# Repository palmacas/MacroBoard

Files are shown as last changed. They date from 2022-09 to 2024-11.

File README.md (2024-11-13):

# MacroBoard

MacroBoard

MacroBoard is a 9-key hot-swappable mechanical macropad powered by [Seeed Studio XIAO RP2040](https://www.seeedstudio.com/XIAO-RP2040-v1-0-p-5026.html). The keyboard has 9 Kailh hot-swappable sockets compatible with any 3-pin or 5-pin MX switch, giving you the ability to choose the switches that suit you best. The keyboard also includes a rotary encoder with a push button and each key is backlit with an RGB LED.

## Features

- Uses Seeed XIAO RP2040, a small form factor board based on the Raspberry Pi RP2040 microcontroller.
- Supports MicroPython and CircuitPython.
- Kailh hot-swappable sockets compatible with 3-pin and 5-pin MX switches.
- Rotary quadrature encoder with push button.
- SK6812 reverse-mounted addressable RGB LEDs to backlight each key.
- Power and communication through a USB-C type port.
- Compatible with KMK keyboard firmware.
- Compatible with Windows, macOS, and Linux operating systems.
- Dimensions: 61mm x 81mm x 31mm (without case), 66mm x 86mm x 35mm (with 3D-printed case).

## Hardware Overview

MacroBoard

## Getting Started

To set up the keyboard to work with CircuitPython and KMK Firmware, follow these steps:

### CircuitPython Installation

1. Enter Bootloader Mode
   - Press and hold the "BOOT" button.
   - Connect the Seeed XIAO RP2040 to your computer while still holding the button.
   - Your computer should now show a new drive, RPI-RP2.
2. Download the [firmware](https://circuitpython.org/board/seeeduino_xiao_rp2040/) for Seeed Studio XIAO RP2040.
3. Drag the .uf2 file to the drive RPI-RP2.
4. Check the drive. The name should now have changed to CIRCUITPY.

### NeoPixel Support 

5. Download the file [*neopixel.py*](https://github.com/adafruit/Adafruit_CircuitPython_NeoPixel/blob/main/neopixel.py) and copy it to the root directory on drive CIRCUITPY.

### KMK Installation

6. Download the [KMK Firmware](https://github.com/KMKfw/kmk_firmware) repository as a ZIP file.
7. Extract all files from de ZIP file and copy the *kmk* folder to the root directory on drive CIRCUITPY.
8. Download the files *code.py* and *boot.py* from the [firmware](firmware) folder.
9. Copy the files to the drive CIRCUITPY.
10. Restart the keyboard by pressing the "RESET" button or disconnecting and reconnecting to the computer.

### Keyboard Configuration

The key mapping defines the function and behavior of each key using a keycode or set of keycodes. The following code, which can be found in the file *code.py*, shows the key mapping for MacroBoard.

```python
# Keymap
keyboard.keymap = [
    [KC.LCTRL(KC.LSHIFT(KC.TAB)), KC.LCTRL(KC.M), KC.LCTRL(KC.TAB),
     KC.MEDIA_PREV_TRACK, KC.MEDIA_PLAY_PAUSE, KC.MEDIA_NEXT_TRACK,
     KC.LCTRL(KC.C), KC.LCTRL(KC.V), KC.LGUI(KC.SPACE),
    ]
]
```
In this example, the keys in the first row can switch between browser tabs and mute a tab. The keys in the second row can control the media player, and the keys in the third row function as `Ctrl+C`, `Ctrl+V`, and `GUI+SPACE`.

||COLUMN 1 |COLUMN 2 | COLUMN 3|
|---|---|---|---|
|ROW 1|CTRL+SHIFT+TAB |CTRL+M |CTRL+TAB |
|ROW 2|PREV TRACK |PLAY/PAUSE |NEXT TRACK |
|ROW 3|CTRL+C |CTRL+V |GUI+SPACE|

You can find a list of all available keycodes at the [KMK Firmware's](http://kmkfw.io/docs/keycodes) wiki.

## Disclaimer

The CircuitPython firmware, KMK Firmware, and NeoPixel library are managed and maintained by their respective developers.

---
More information:  
[MacroBoard – Design and Assembly](https://palmacas.com/macroboard-design/) [[Spanish]](https://palmacas.com/macroboard-diseno/)  
[MacroBoard – Configuration](https://palmacas.com/macroboard-configuration/) [[Spanish]](https://palmacas.com/macroboard-configuracion/)

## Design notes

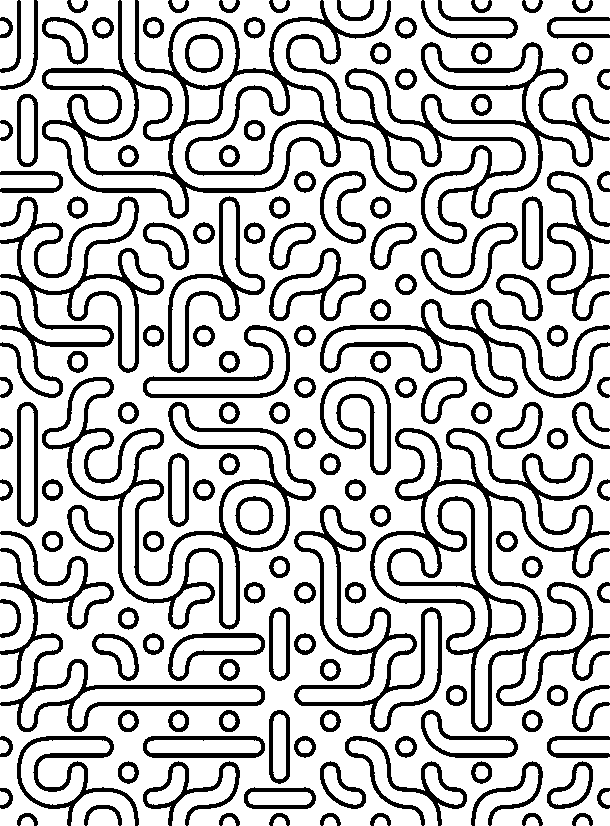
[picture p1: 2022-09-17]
PCB/TruchetTiles.bmp

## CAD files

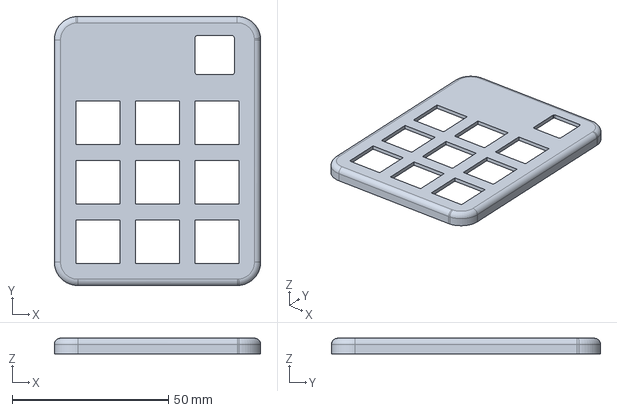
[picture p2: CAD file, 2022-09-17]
CAD/MacroBoardCover.step
66.0 x 86.0 x 5.00 mm

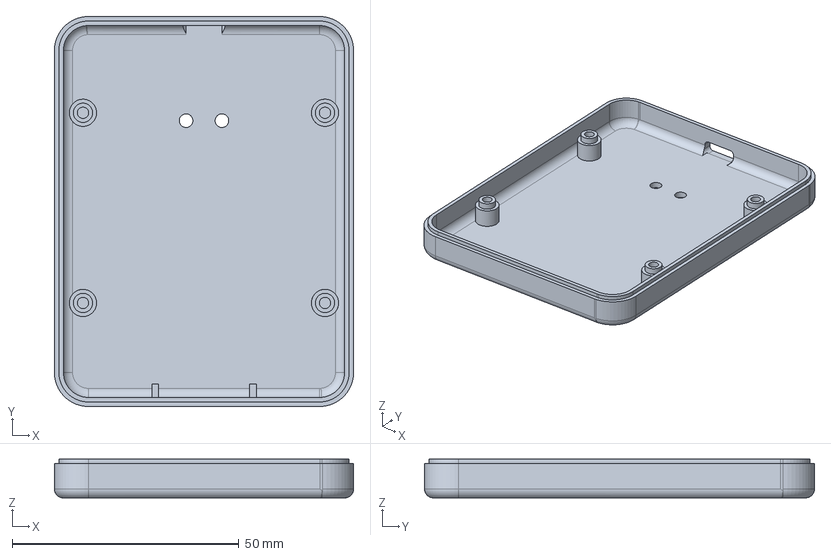
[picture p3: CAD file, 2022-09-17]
CAD/MacroBoardBase.step
66.0 x 86.0 x 8.56 mm

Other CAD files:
CAD/MacroBoardBase.stl
CAD/MacroBoardCover.stl

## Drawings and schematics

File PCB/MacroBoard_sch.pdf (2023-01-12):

# ROTA COL1

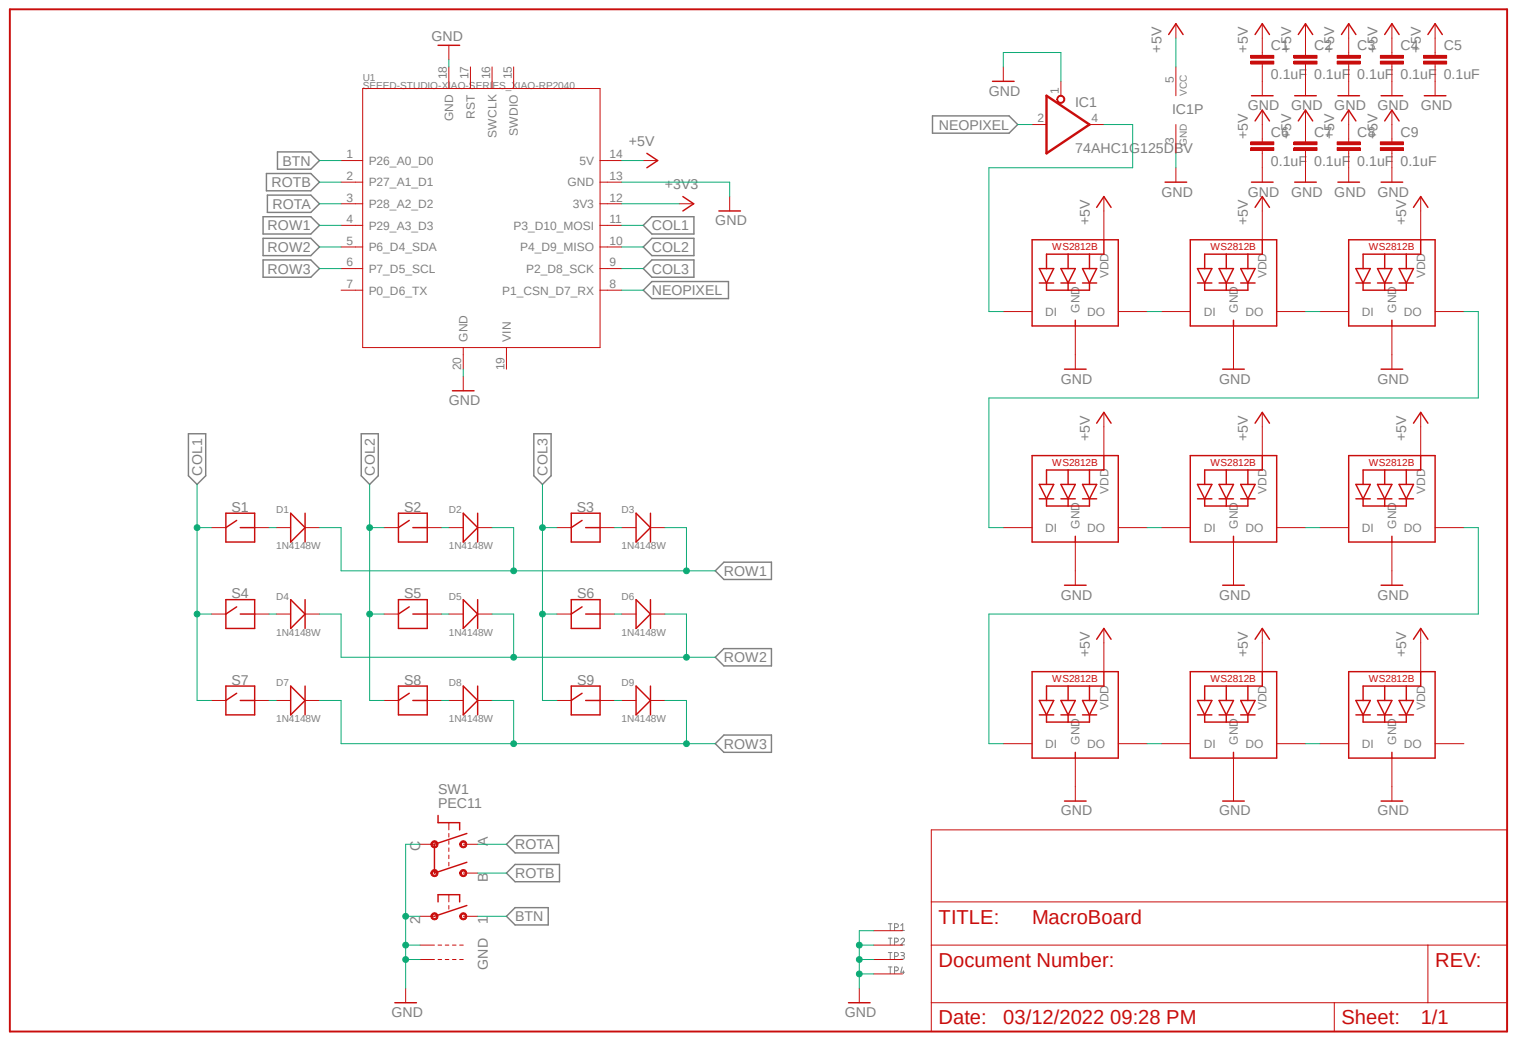
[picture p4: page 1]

GND GND

DI GND DO VDD

Document Number: | REV:

Date: 03/12/2022 09:28 PM | Sheet: 1/1

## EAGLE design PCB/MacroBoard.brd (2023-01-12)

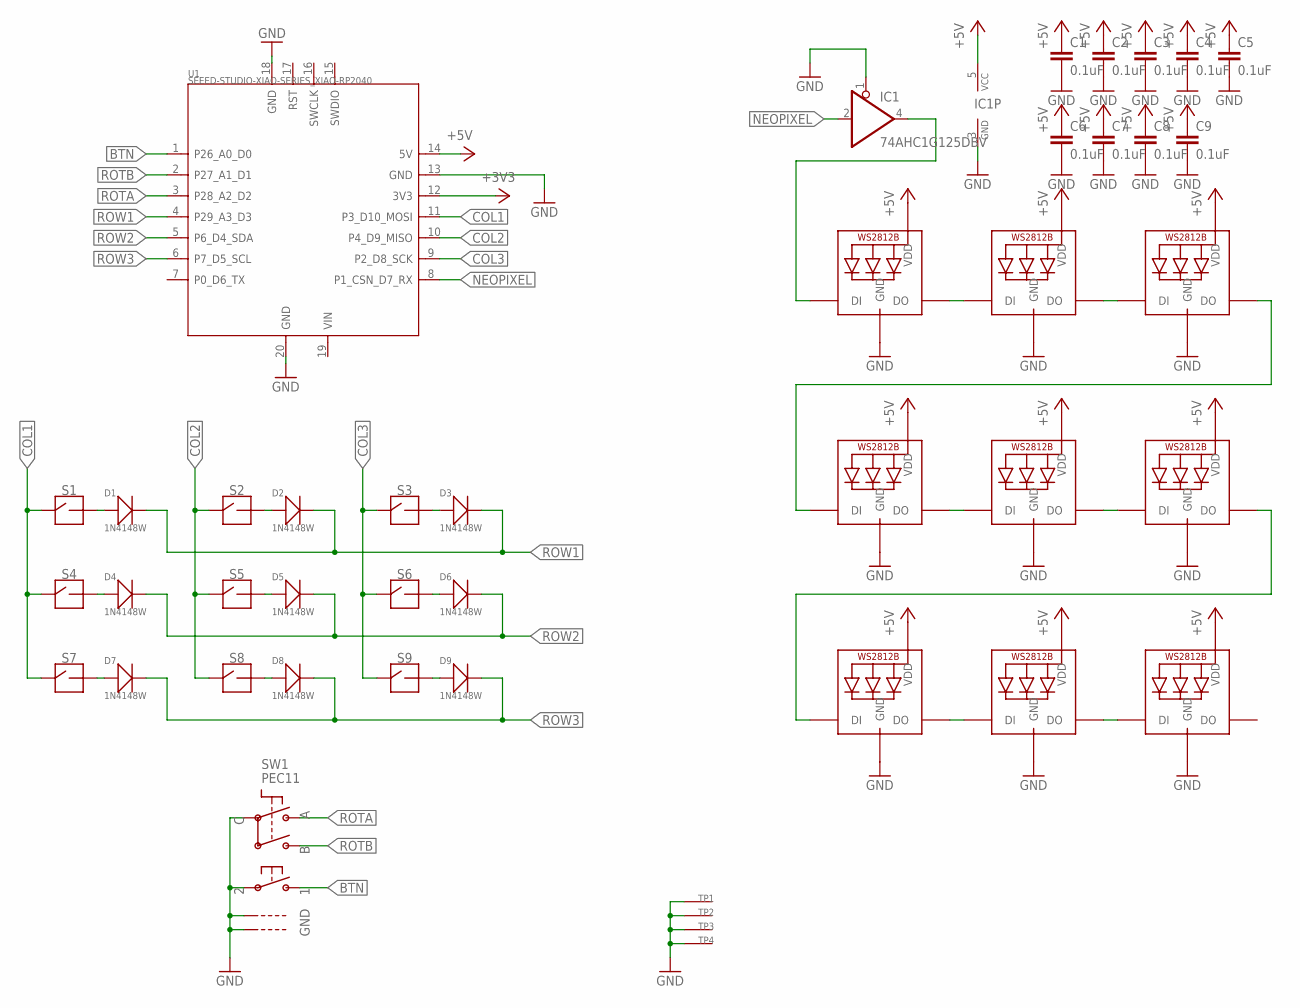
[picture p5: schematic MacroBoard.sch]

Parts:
C1, C2, C3, C4, C5, C6, C7, C8, C9: 0.1uF; C0805K
D1, D2, D3, D4, D5, D6, D7, D8, D9: 1N4148W; SOD-123
IC1: 74AHC1G125DBV; SOT23-5
LED1, LED2, LED3, LED4, LED5, LED6, LED7, LED8, LED9: MICROBUILDER_WS2812B_SK6812E; MICROBUILDER_NEO3535_REVERSE
S1, S2, S3, S4, S5, S6, S7, S8, S9: SOCKET; ADAFRUIT_ELECTROMECH_KAILH_SOCKET
SW1: PEC11; ADAFRUIT_ELECTROMECH_PEC11+SWITCH
TP1, TP2, TP3, TP4: SEWTAP_SMTNUTM3; SMT_NUT_3MM
U1: SEEED-STUDIO-XIAO-SERIES_XIAO-RP2040; SEEED-STUDIO-XIAO-SERIES_XIAO-SAMD21/RP2040-MODULE14P-2.54-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

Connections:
+3V3: U1.12 (3V3)
+5V: C1.1, C2.1, C3.1, C4.1, C5.1, C6.1, C7.1, C8.1, C9.1, IC1.5 (VCC), LED1.1-VDD (VDD), LED2.1-VDD (VDD), LED3.1-VDD (VDD), LED4.1-VDD (VDD), LED5.1-VDD (VDD), LED6.1-VDD (VDD), LED7.1-VDD (VDD), LED8.1-VDD (VDD), LED9.1-VDD (VDD), U1.14 (5V)
BTN: SW1.P$1, U1.1 (P26_A0_D0)
COL1: S1.1, S4.1, S7.1, U1.11 (P3_D10_MOSI)
COL2: S2.1, S5.1, S8.1, U1.10 (P4_D9_MISO)
COL3: S3.1, S6.1, S9.1, U1.9 (P2_D8_SCK)
GND: C1.2, C2.2, C3.2, C4.2, C5.2, C6.2, C7.2, C8.2, C9.2, IC1.1 (OE), IC1.3 (GND), LED1.3-GND (GND), LED2.3-GND (GND), LED3.3-GND (GND), LED4.3-GND (GND), LED5.3-GND (GND), LED6.3-GND (GND), LED7.3-GND (GND), LED8.3-GND (GND), LED9.3-GND (GND), SW1.P$2, SW1.P$C, SW1.P$GND1, SW1.P$GND2, TP1.P$1, TP2.P$1, TP3.P$1, TP4.P$1, U1.13 (GND), U1.18 (GND), U1.20 (GND)
unnamed: LED8.2-DOUT (DO), LED9.4-DIN (DI)
unnamed: LED7.2-DOUT (DO), LED8.4-DIN (DI)
unnamed: LED5.2-DOUT (DO), LED6.4-DIN (DI)
unnamed: LED6.2-DOUT (DO), LED7.4-DIN (DI)
unnamed: LED4.2-DOUT (DO), LED5.4-DIN (DI)
unnamed: LED3.2-DOUT (DO), LED4.4-DIN (DI)
unnamed: LED1.2-DOUT (DO), LED2.4-DIN (DI)
unnamed: LED2.2-DOUT (DO), LED3.4-DIN (DI)
unnamed: IC1.4 (O), LED1.4-DIN (DI)
unnamed: D1.+, S1.2
unnamed: D4.+, S4.2
unnamed: D7.+, S7.2
unnamed: D2.+, S2.2
unnamed: D5.+, S5.2
unnamed: D8.+, S8.2
unnamed: D3.+, S3.2
unnamed: D6.+, S6.2
unnamed: D9.+, S9.2
NEOPIXEL: IC1.2 (I), U1.8 (P1_CSN_D7_RX)
ROTA: SW1.P$A, U1.3 (P28_A2_D2)
ROTB: SW1.P$B, U1.2 (P27_A1_D1)
ROW1: D1.-, D2.-, D3.-, U1.4 (P29_A3_D3)
ROW2: D4.-, D5.-, D6.-, U1.5 (P6_D4_SDA)
ROW3: D7.-, D8.-, D9.-, U1.6 (P7_D5_SCL)

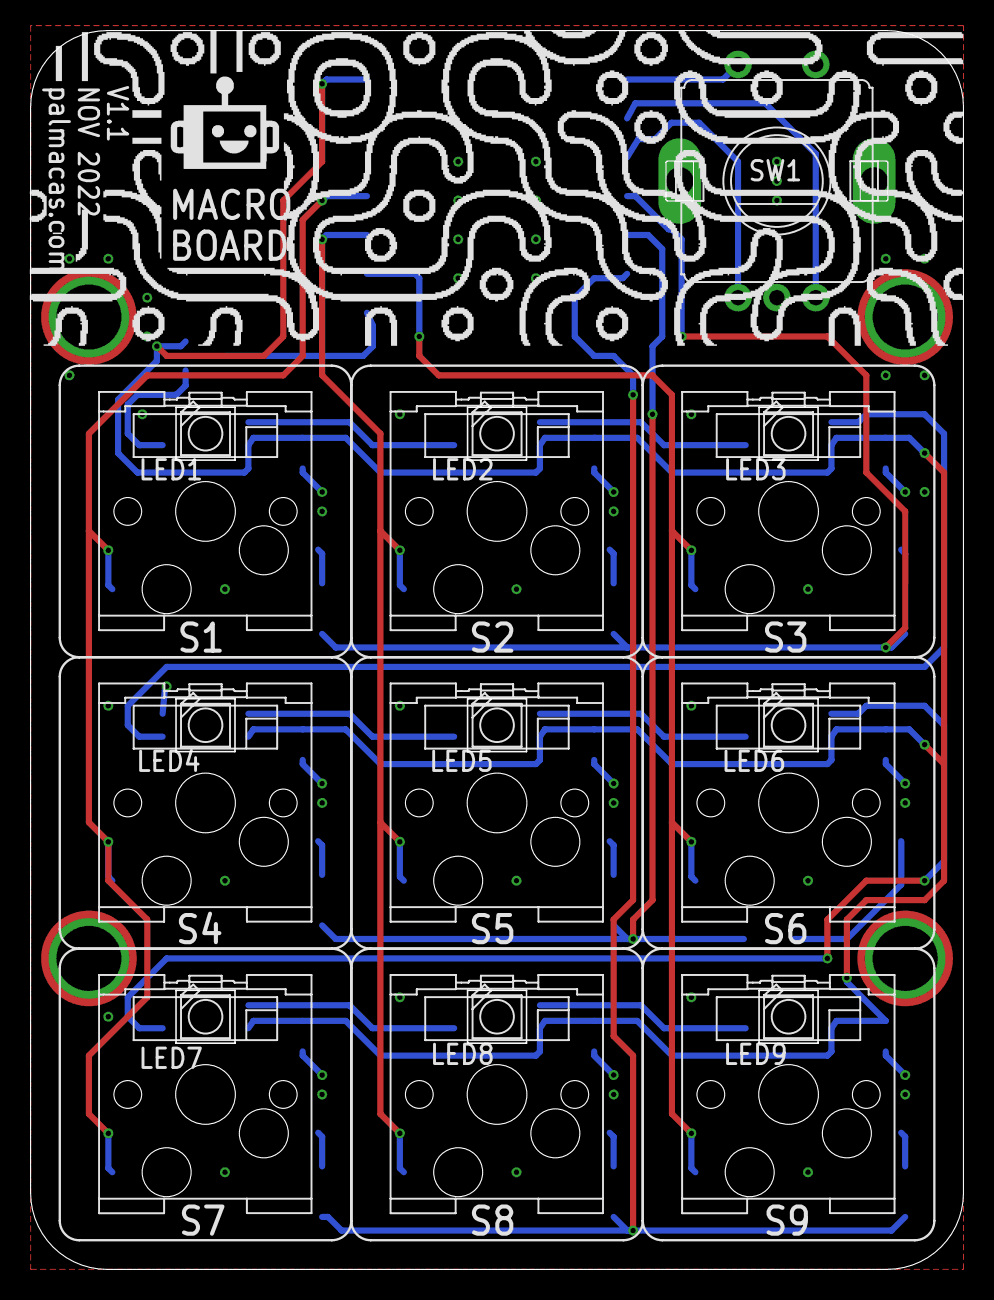
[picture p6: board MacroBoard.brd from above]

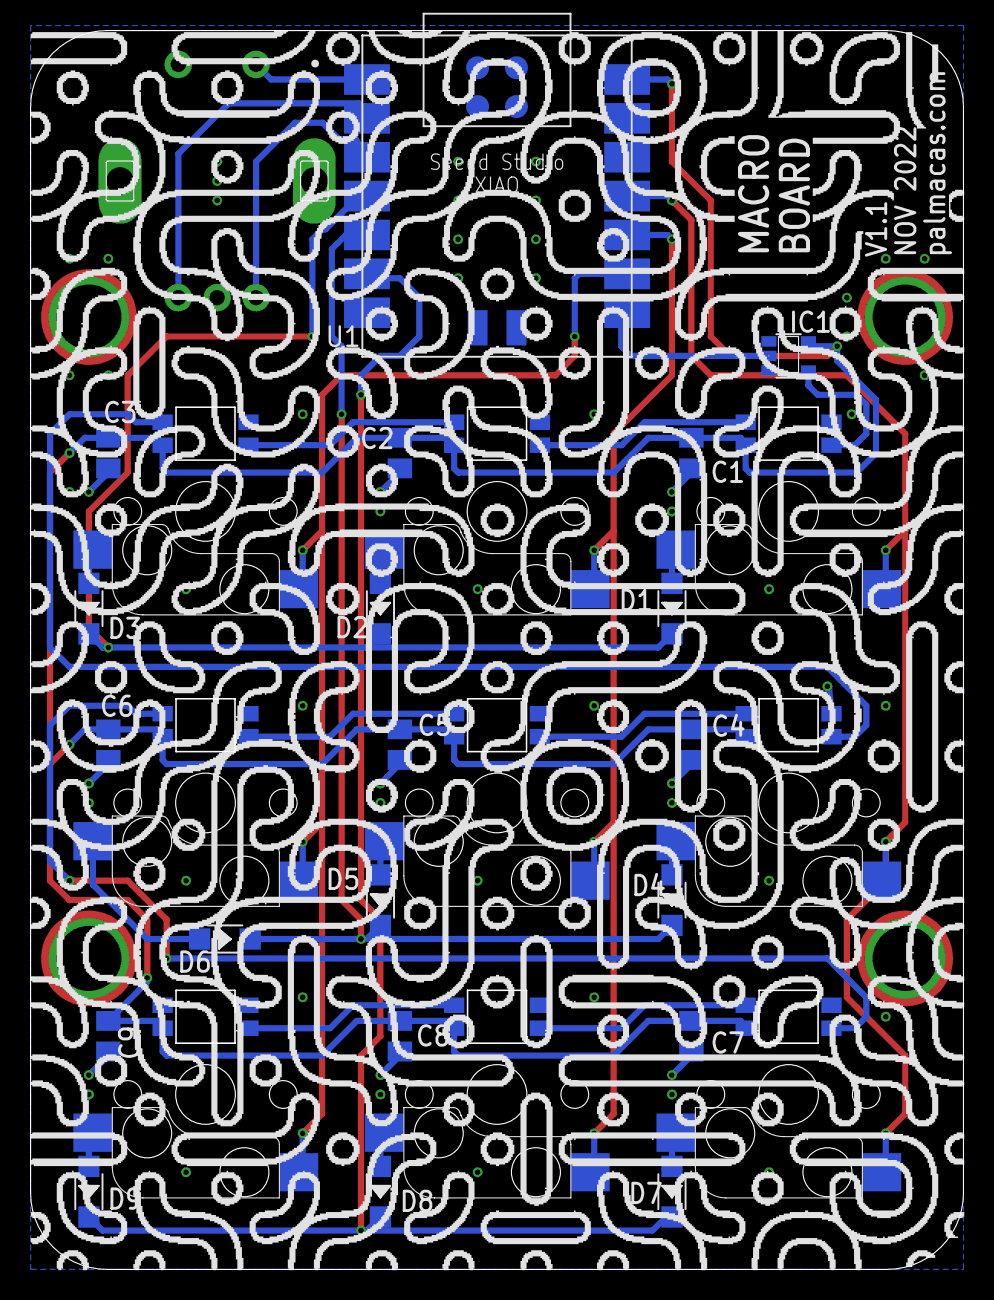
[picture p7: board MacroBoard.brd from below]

Board: 2 copper layers, 61.0 x 81.0 mm, 44 parts (20 on the bottom side), 30 nets.

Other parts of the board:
U$2: PALMACAS_AVATAR_BLACK#PNG

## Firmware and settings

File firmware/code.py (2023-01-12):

"""
MacroBoard

* Cristian Palma (palmacas)
"""

import board
from kmk.kmk_keyboard import KMKKeyboard
from kmk.keys import KC
from kmk.scanners import DiodeOrientation
from kmk.extensions.RGB import RGB, AnimationModes
from kmk.extensions.media_keys import MediaKeys
from kmk.modules.encoder import EncoderHandler

# Pinout
COL1 = board.D10
COL2 = board.D9
COL3 = board.D8
ROW1 = board.D3
ROW2 = board.D4
ROW3 = board.D5
PUSHBUTTON = board.D0
ROTA = board.D2
ROTB = board.D1
NEOPIXEL = board.D7

keyboard = KMKKeyboard()

# Basic matrix settings
keyboard.col_pins = (COL1, COL2, COL3)
keyboard.row_pins = (ROW1, ROW2, ROW3)
keyboard.diode_orientation = DiodeOrientation.COL2ROW

# RGB LEDs settings
rgb_ext = RGB( 
    pixel_pin = NEOPIXEL,
    num_pixels = 9,
    hue_default = 100,
    sat_default = 255,
    val_default = 15,
    val_limit = 25,
    animation_speed = 1,
    animation_mode=AnimationModes.RAINBOW,
    refresh_rate = 30,
)
keyboard.extensions.append(rgb_ext)
keyboard.extensions.append(MediaKeys())

# Encoder settings
encoder_handler = EncoderHandler()
keyboard.modules.append(encoder_handler)
encoder_handler.pins = ((ROTA, ROTB, PUSHBUTTON, False),)
encoder_handler.map = (((KC.VOLD, KC.VOLU, KC.MUTE),),)

# Keymap
keyboard.keymap = [
    [KC.LCTRL(KC.LSHIFT(KC.TAB)), KC.LCTRL(KC.M), KC.LCTRL(KC.TAB),
     KC.MEDIA_PREV_TRACK, KC.MEDIA_PLAY_PAUSE, KC.MEDIA_NEXT_TRACK,
     KC.LCTRL(KC.C), KC.LCTRL(KC.V), KC.LGUI(KC.SPACE),
    ]
]

if __name__ == '__main__':
    keyboard.go()

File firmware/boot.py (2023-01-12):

import supervisor
import board
import digitalio
import storage
import usb_cdc
import usb_hid
import usb_midi

supervisor.set_next_stack_limit(4096 + 4096)

# If the encoder push-button is held during boot, don't run the code which hides the storage and disables serial and midi
button = digitalio.DigitalInOut(board.D0)
button.direction = digitalio.Direction.INPUT
button.pull = digitalio.Pull.UP

if button.value:
    storage.disable_usb_drive() # Hides device storage
    usb_cdc.disable() # Disables serial comunication
    usb_midi.disable() # Disables midi
    usb_hid.enable(boot_device=1) # Enables keyboard before OS boot
    
button.deinit()
